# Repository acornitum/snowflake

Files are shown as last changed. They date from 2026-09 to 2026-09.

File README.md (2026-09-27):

# Snowflake - one key macropad



Snowflake is a one key macropad! Solder on any mx-style switch and use it as a one key keyboard - the PCB itself measures 19x19mm :D

Featuring: 

- CH552E as the microcontroller
- Neopixel on the bottom
- All unused pins broken out
- USB-C for power and data
- Keychain hole (M2 screw size); hang it on your bag!

This project was made in ~5h in one go, art included.



I've ordered 160 of these - at that quantity, when panelized, they cost <1.5 USD each, parts and assembly included. I'll be giving them out - if you see me IRL, feel free to ask for one!

Screenshot of schematic + PCB in KiCad: 



This repo will be updated with a 3d printable case later :D

For uploading your own firmware, go to the readme in the firmware folder of this repo!

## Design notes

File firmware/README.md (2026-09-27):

# Snowflake Firmware

Welcome! Here's a basic way to upload custom code onto the macropad so that you could make it type whatever you want. 

For this, I'm using [https://github.com/DeqingSun/ch55xduino](https://github.com/DeqingSun/ch55xduino)! Follow the instructions on that GitHub Repo to start. There are other ways to do it, but this is probably the fastest for getting started.

Once you have that set up, the code is in firmware.ino. Edit it to put what you want on!

In order to flash things on, you need to put the board into bootloader mode. To do that:

1. Hold down the boot button
2. Plug it into the USB-C cable connected to your laptop
3. Press upload in the IDE!

It may take a few tries; I've found that after a few seconds, if you don't flash the new code on fast enough, the board leaves bootloader mode. 

Good luck + have fun!

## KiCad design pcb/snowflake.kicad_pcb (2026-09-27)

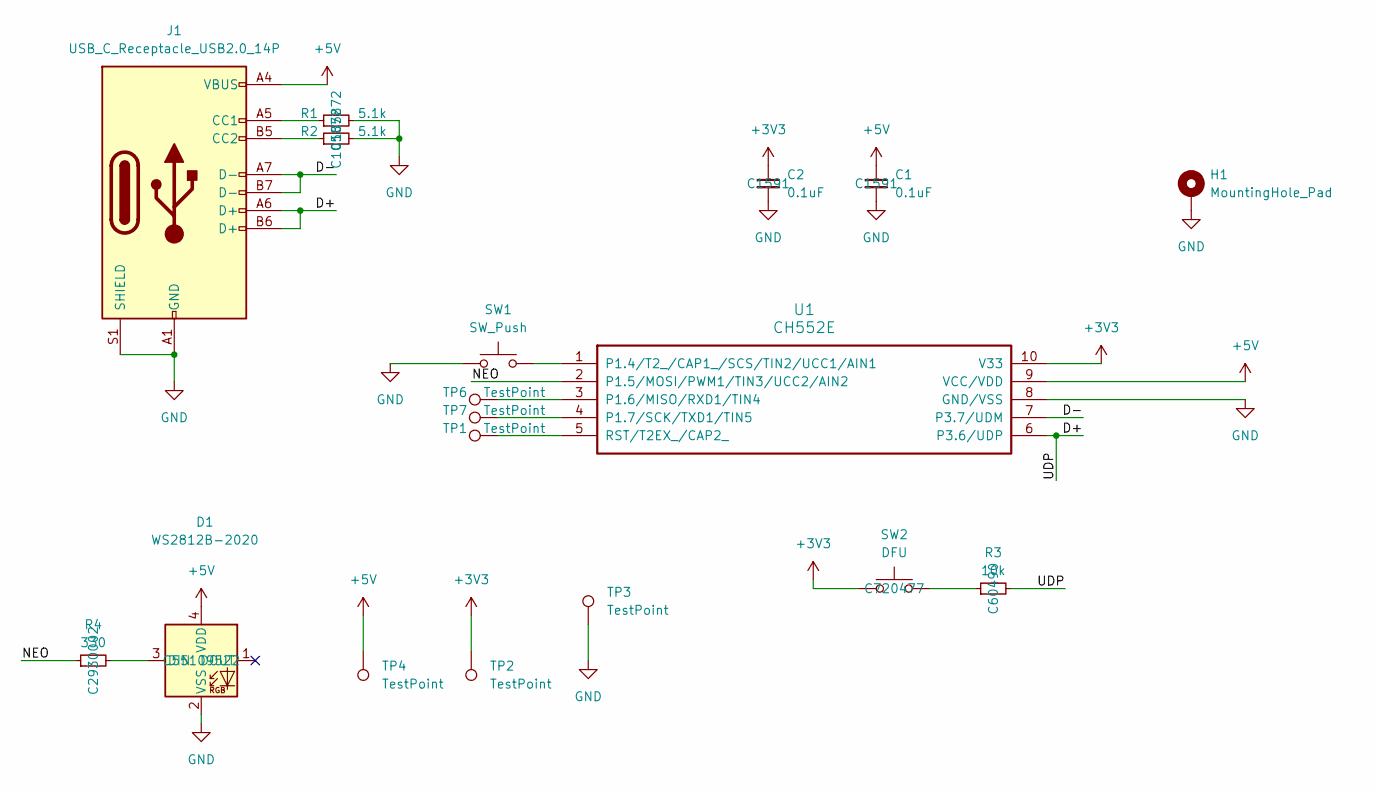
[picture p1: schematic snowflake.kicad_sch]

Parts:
C1, C2: 0.1uF; C_0603_1608Metric; LCSC C1591
D1: WS2812B-2020; LED_WS2812B-2020_PLCC4_2.0x2.0mm; LCSC C55109522
H1: MountingHole_Pad; MountingHole_2.2mm_M2_DIN965_Pad
J1: USB_C_Receptacle_USB2.0_14P; USB_C_Receptacle_HRO_TYPE-C-31-M-12; LCSC C393939
R1, R2: 5.1k; R_0402_1005Metric; LCSC C105872
R3: 10k; R_0402_1005Metric; LCSC C60490
R4: 330; R_0402_1005Metric; LCSC C2930002
SW1: SW_Push; SW_Cherry_MX_1.00u_PCB
SW2: DFU; SW_Push_SPST_NO_Alps_SKRK; LCSC C720477
TP1, TP2, TP3, TP4, TP6, TP7: TestPoint; TestPoint_Pad_D1.5mm
U1: CH552E; MSOP-10_3x3mm_P0.5mm; LCSC C967938

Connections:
+3V3: C2.1, SW2.1, TP2.1, U1.10 (V33)
+5V: C1.1, D1.4 (VDD), J1.A4 (VBUS), J1.A9 (VBUS), J1.B4 (VBUS), J1.B9 (VBUS), TP4.1, U1.9 (VCC/VDD)
/D+: J1.A6 (D+), J1.B6 (D+), R3.2, U1.6 (P3.6/UDP)
/D-: J1.A7 (D-), J1.B7 (D-), U1.7 (P3.7/UDM)
/NEO: R4.1, U1.2 (P1.5/MOSI/PWM1/TIN3/UCC2/AIN2)
GND: C1.2, C2.2, D1.2 (VSS), H1.1, J1.A1 (GND), J1.A12 (GND), J1.B1 (GND), J1.B12 (GND), J1.S1 (SHIELD), R1.2, R2.2, SW1.1, TP3.1, U1.8 (GND/VSS)
unnamed: D1.3 (DIN), R4.2
unnamed: J1.A5 (CC1), R1.1
unnamed: J1.B5 (CC2), R2.1
unnamed: R3.1, SW2.2
unnamed: SW1.2, U1.1 (P1.4/T2_/CAP1_/SCS/TIN2/UCC1/AIN1)
unnamed: TP6.1, U1.3 (P1.6/MISO/RXD1/TIN4)
unnamed: TP7.1, U1.4 (P1.7/SCK/TXD1/TIN5)
unnamed: TP1.1, U1.5 (RST/T2EX_/CAP2_)

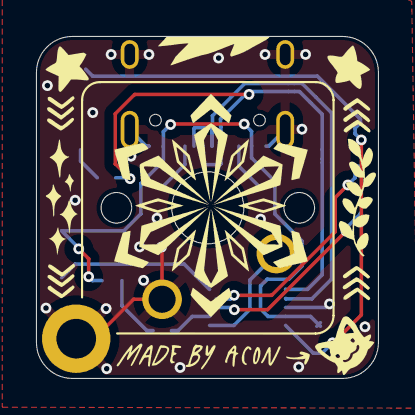
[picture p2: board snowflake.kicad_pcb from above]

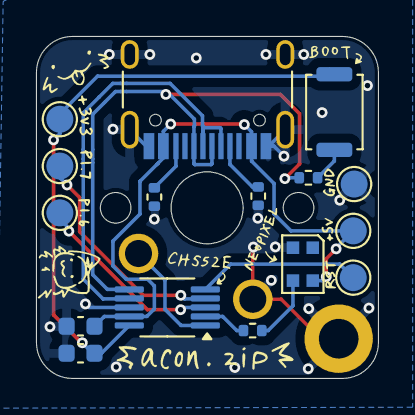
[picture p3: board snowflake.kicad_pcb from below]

Board: 2 copper layers, 19.0 x 19.0 mm, 18 parts (16 on the bottom side), 14 nets.

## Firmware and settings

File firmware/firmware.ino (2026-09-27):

// While the button (P1.4) is held down, the NeoPixel (D1, P1.5) cycles
// through rainbow colors. Each press also types a URL over USB HID.
//
// Board settings (Tools menu):
//   Board:       CH552 Board
//   Clock:       16 MHz (internal)
//   USB Settings: USER CODE w/ 148B USB ram
//
// This sketch also needs the "userUsbHidKeyboard" helper files sitting
// next to it (see setup notes below) - they come from the ch55xduino
// examples folder: File > Examples > CH55xduino > 05.USB > HidKeyboard.
// Copy that example's "src" folder into this sketch's folder so you end up
// with:
//   firmware/
//     firmware.ino
//     src/userUsbHidKeyboard/USBHIDKeyboard.c
//     src/userUsbHidKeyboard/USBHIDKeyboard.h
//     src/userUsbHidKeyboard/USBconstant.c
//     src/userUsbHidKeyboard/USBconstant.h
//     src/userUsbHidKeyboard/USBhandler.c
//     src/userUsbHidKeyboard/USBhandler.h

#ifndef USER_USB_RAM
#error "This sketch needs to be compiled with a USER USB setting"
#endif

#include <WS2812.h>
#include "src/userUsbHidKeyboard/USBHIDKeyboard.h"

#define BUTTON_PIN 14 // P1.4 (SW1)
#define LED_PIN 15    // P1.5 (NeoPixel data, via R4)

__xdata uint8_t ledData[3];

bool buttonPressedPrev = false;
uint8_t hue = 0;

void setPixelOff() {
  set_pixel_for_GRB_LED(ledData, 0, 0, 0, 0);
  neopixel_show_P1_5(ledData, 3);
}

// Classic color wheel: pos 0-255 sweeps through the rainbow.
// Scaled down (>>3) to keep it comfortably dim.
void wheel(uint8_t pos, uint8_t *r, uint8_t *g, uint8_t *b) {
  pos = 255 - pos;
  if (pos < 85) {
    *r = 255 - pos * 3;
    *g = 0;
    *b = pos * 3;
  } else if (pos < 170) {
    pos -= 85;
    *r = 0;
    *g = pos * 3;
    *b = 255 - pos * 3;
  } else {
    pos -= 170;
    *r = pos * 3;
    *g = 255 - pos * 3;
    *b = 0;
  }
}

void setup() {
  pinMode(BUTTON_PIN, INPUT_PULLUP);
  pinMode(LED_PIN, OUTPUT);
  USBInit();
  setPixelOff();
}

void loop() {
  bool buttonPressed = !digitalRead(BUTTON_PIN);

  if (buttonPressed != buttonPressedPrev) {
    buttonPressedPrev = buttonPressed;
    if (buttonPressed) {
      Keyboard_print("https://github.com/acornitum/snowflake");
    } else {
      setPixelOff();
    }
    delay(20); // naive debounce
  }

  if (buttonPressed) {
    uint8_t r, g, b;
    wheel(hue, &r, &g, &b);
    set_pixel_for_GRB_LED(ledData, 0, r >> 3, g >> 3, b >> 3);
    neopixel_show_P1_5(ledData, 3);
    hue += 3;
    delay(20); // rotation speed
  }
}
